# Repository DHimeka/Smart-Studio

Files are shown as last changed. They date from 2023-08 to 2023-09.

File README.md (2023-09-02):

# Smart LED Studio Light System

For the individual project during the fourth semester for the module Electronic Design Realization EN2160, I opted to enhance a Smart LED studio lighting system, primarily tailored for videographers, photographers, and professionals seeking improved lighting solutions. I began with an economical base product, featuring an ESP32 microcontroller. Following a user-centric design methodology, I aimed to rectify existing market deficiencies, introducing heightened luminosity, flexibility, and user-oriented attributes. This specialized lighting system not only targets the need for efficient workspace illumination but also offers stress relief and entertainment, effectively integrating practicality and leisure. The project's objective is to provide an affordable yet comprehensive lighting solution, thereby reshaping the landscape of studio lighting.

## Table of Contents
- [Introduction](#introduction)
- [Problem Statement](#problem-statement)
- [Design Approach](#design-approach)
- [Prototype Design](#prototype-design)
  
   -[PCB Design](#pcb)
  
   -[Enclosure Design](#enclosure)
  
   -[Testing](#test)
  
- [Final Design](#final-design)

- [Suppliers](#suppliers)
- [Assembly Instructions](#assembly-instructions)
- [Future Improvements](#future-improvements)

## Introduction

Welcome to the Smart LED Studio Light System project! As a passionate photographer and videographer, I often found myself in need of high-quality studio lighting that didn't break the bank. This project was born out of that necessity, aiming to provide an affordable, customizable, and user-friendly studio lighting solution. In this `README.md`, I'll guide you through the project and share my journey in creating this versatile lighting system.

## Problem Statement

In my photography and videography work, I encountered the challenge of finding studio lighting that met my specific needs without costing a fortune. The existing commercial solutions were either too expensive or lacked the flexibility and features I desired. This project addresses this issue by offering an accessible DIY alternative that empowers creators to tailor their lighting setup.

## Design Approach

My design approach focused on three key pillars: affordability, versatility, and user-friendliness. To achieve these goals, I conducted thorough research on LED technology, lighting design principles, and user preferences. I also sought inspiration from the maker community, drawing on their creative solutions and feedback to refine my own design.

## Prototype Design

In the early stages, I carefully selected components, considering factors such as LED panel types, power sources, and control interfaces. The prototype development involved creating a functional LED panel design, crafting schematics, and performing initial testing. The insights gained from these initial prototypes allowed me to iterate and refine the design.

## Final Design

The final design of the Smart LED Studio Light System incorporates feedback from fellow photographers and videographers. I enhanced the system by adding Bluetooth connectivity, enabling users to control the lights remotely via a smartphone app. Additionally, I implemented a music visualization feature that synchronizes the lights with audio, creating dynamic and captivating lighting effects. The improved enclosure design ensures durability and aesthetic appeal.

## Suppliers

I sourced the components from reputable suppliers, ensuring the quality and reliability of the materials.

## Assembly Instructions

I've provided detailed step-by-step instructions to help you assemble your Smart LED Studio Light System.Since the device compromises of 2 PCBs
when assembling the device should be concerned about the connecting procedures.
-Power off the switch
-Place the batteries in the battery holder
-Confirm if the appropriate voltages are at headers J20 and J31 using a multi meter, before moving forward.Connect power to ESP and connect
power to the LED panel by connecting appropriate pins
-Connect the signal pins to LED Panel(header P10 in main PCB and P1 header in LED panel PCB)
-Press the power on switch and you can witness the functioning.

## Future Improvements

While the current version of the Smart LED Studio Light System is feature-rich, there are always opportunities for further enhancements. Some ideas for future improvements include:
- Integration with voice assistants for hands-free control.
- Compatibility with a wider range of music sources and platforms.
- Advanced color temperature and brightness presets for different shooting scenarios.
- Collaborative features for synchronized lighting setups in group settings.

## User Manual

For detailed instructions on how to operate your Smart LED Studio Light System, please refer to the user manual provided [here](user-manual.pdf).

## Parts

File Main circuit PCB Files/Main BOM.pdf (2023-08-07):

Line # | Name Description | Designator | Revision ID | Revision State | Revision Status | Manufacturer 1 | Manufacturer Part Number 1 | Manufacturer Lifecycle 1 | Supplier 1 | Supplier Part Number 1 | Supplier Unit Price 1 | Supplier Subtotal 1
| 100nF Bridge Rectifier | BR1 | | Not managed
| Cap Ceramic 100nF 100V CL31B104 KCFNNNE X7R ±10% SMD 1206 +125°C Embossed T/R | C1 | CMP-13271-001514-1 | New From Design | Up to date | Samsung | CL31B104KCFNNNE | Volume Production | Digi-Key | 1276-1151-1-ND | | 0.12 | 0.24
| Cap Ceramic CL31B104 100nF 100V X7R ±10% KCFNNNE SMD 1206 +125°C Embossed T/R | C2 | CMP-13271-001514-1 | New From Design | Up to date | Samsung | CL31B104KCFNNNE | Volume Production | Digi-Key | 1276-1151-1-ND | | 0.12 | 0.24
| CL21B106 CAP CER 10UF 16V X7R 0805 KOQNNNG | C3 | CMP-13271-000015-1 | New From Design | Up to date | Samsung | CL21B106KOQNNNG | Volume Production | Arrow Electronics | CL21B106KOQNNNG | 0.1719 | 0.3438
| EEEFT1E4 71AP CAP ALUM 470UF 20% 25V SMD | C4 | CMP-05427-000040-1 | New From Design | Up to date | Panasonic | EEE-FT1E471AP | Volume Production | Newark | 89Y7242 | | 0.46 | 0.46
| CL21B106 KOQNNNG CAP CER 10UF 16V X7R 0805 | C5 | CMP-13271-000015-1 | New From Design | Up to date | Samsung | CL21B106KOQNNNG | Volume Production | Arrow Electronics | CL21B106KOQNNNG | 0.1719 | 0.3438
68pF 0.1uF Capacitor Capacitor Chip Multilayer GRM31CR 71E106KA Ceramic Capacitors for General 12L Purpose, 1206, 10uF, X7R, 15%, 10%, 25V | C7 C6 C8 | CMP-06035-003589-1 | Not managed Not managed New From Design | Up to date | Murata | GRM31CR71E106KA12L | Volume Production | Mouser | 81-GRM31CR71E106KA12 | 0.29 | 0.29
EMK316BB J476ML-T None | C9 | CMP-14477-000191-2 | New From Design | Up to date | Taiyo Yuden | EMK316BBJ476ML-T | Volume Production | Mouser | 963-EMK316BBJ476ML-T | 0.58 | 0.58
56uF Capacitor Polarised | C10 | | Not managed
100nF Capacitor 120uF Capacitor Polarised | C11 C12 | | Not managed Not managed
15nF Capacitor CL21 Series 0805 220pF CL21C221 JBANNNC 50V ±5% Tolerance C0G Multilayer Ceramic Chip Capacitor | C13 C14 | CMP-13271-001616-1 | Not managed New From Design | Up to date | Samsung | CL21C221JBANNNC | Volume Production | Digi-Key | 1276-1164-1-ND | 0.1 | 0.1
10uF Capacitor CL21 Series 0805 2.2nF 50V CL21C222 JBFNNNE ±5% Tolerance C0G Multilayer Ceramic Chip Capacitor | C15 C16 | CMP-13271-001564-1 | Not managed New From Design | Up to date | Samsung | CL21C222JBFNNNE | End of Life | Arrow Electronics | CL21C222JBFNNNE | 0.0153 | 0.0153
SS36FA Diode | D1 | | Not managed
SML-Yellow LED, Water Clear Len, 585 nm, LX1206YC-TR 2.1 V, -40 to 85 degC, 2-Pin SMD, RoHS, Tape and Reel | DS1 | CMP-2000-07124-1 | Released | Up to date | Lumex | SML-LX1206YC-TR | Volume Production | Mouser | 696-SML-LX1206YC | | 0.36 | 0.36
BLM21PG3 Chip Ferrite Bead, 0805, 30 00SH1D Ω @ 100MHz, 0.014Ω, , 4A | FB1 | CMP-06046-001820-1 | New From Design | Up to date | Murata | BLM21PG300SH1D | Volume Production | Arrow Electronics | BLM21PG300SH1D | 0.0738 | 0.738
BLM21PG3 Chip Ferrite Bead, 0805, 30 00SH1D Ω @ 100MHz, 0.014Ω, , 4A | FB2 | CMP-06046-001820-1 | New From Design | Up to date | Murata | BLM21PG300SH1D | Volume Production | Arrow Electronics | BLM21PG300SH1D | 0.0738 | 0.738
BLM21PG3 Chip Ferrite Bead, 0805, 30 00SH1D Ω @ 100MHz, 0.014Ω, , 4A | FB3 | CMP-06046-001820-1 | New From Design | Up to date | Murata | BLM21PG300SH1D | Volume Production | Arrow Electronics | BLM21PG300SH1D | 0.0738 | 0.738
BLM21PG3 Chip Ferrite Bead, 0805, 30 00SH1D Ω @ 100MHz, 0.014Ω, , 4A | FB4 | CMP-06046-001820-1 | New From Design | Up to date | Murata | BLM21PG300SH1D | Volume Production | Arrow Electronics | BLM21PG300SH1D | 0.0738 | 0.738
BLM21PG3 00SH1D Chip Ferrite Bead, 0805, 30 Ω @ 100MHz, 0.014Ω, , 4A | FB5 | CMP-06046-001820-1 | New From Design | Up to date | Murata | BLM21PG300SH1D | Volume Production | Arrow Electronics | BLM21PG300SH1D | 0.0738 | 0.738
BLM21PG3 00SH1D Chip Ferrite Bead, 0805, 30 Ω @ 100MHz, 0.014Ω, , 4A | FB6 | CMP-06046-001820-1 | New From Design | Up to date | Murata | BLM21PG300SH1D | Volume Production | Arrow Electronics | BLM21PG300SH1D | 0.0738 | 0.738
LMR38020 FDDAR Integrated Circuit | IC1 | | Not managed
LM26003 MH_NOPB Integrated Circuit | IC2 | | Not managed
61301621 THT Vertical Pin Header WR-PHD, Pitch 2.54 121 mm, Dual Row, 16 pins | J1 | CMP-1502-01097-1 | Released | Out of date | Wurth Electronics | 61301621121 | Volume Production | Newark | 20X0981 | 0.318 | 0.318
5000 PC TEST POINT MINIATURE RED | J2 | CMP-19636-000027-1 | New From Design | Up to date | Keystone Electronics | 5000 | Volume Production | Farnell | 2250281 | 0.24385 | | 4.39
61900211 CONN HEADER 121 VERT 2POS 2.54MM | J3 | CMP-1502-00584-2 | Released | Out of date | Wurth Electronics | 61900211121 | Volume Production | Mouser | 710-61900211121 | | 0.54 | 4.32
RAPC722X A, 3-Pin THD, Power Jack, 5 RoHS, Bulk | J4 | CMP-2000-05384-1 | Released | Up to date | Switchcraft | RAPC722X | Volume Production | Newark | 65K7786 | | 1.35 | 2.7
PC TEST POINT 5000 MINIATURE RED | J5 | CMP-19636-000027-1 | New From Design | Up to date | Keystone Electronics | 5000 | Volume Production | Farnell | 2250281 | 0.24385 | | 4.39
5000 PC TEST POINT MINIATURE RED | J6 | CMP-19636-000027-1 | New From Design | Up to date | Keystone Electronics | 5000 | Volume Production | Farnell | 2250281 | 0.24385 | | 4.39
5000 PC TEST POINT MINIATURE RED | J7 | CMP-19636-000027-1 | New From Design | Up to date | Keystone Electronics | 5000 | Volume Production | Farnell | 2250281 | 0.24385 | | 4.39
PC TEST POINT 5000 MINIATURE RED | J8 | CMP-19636-000027-1 | New From Design | Up to date | Keystone Electronics | 5000 | Volume Production | Farnell | 2250281 | 0.24385 | | 4.39
5000 PC TEST POINT MINIATURE RED | J9 | CMP-19636-000027-1 | New From Design | Up to date | Keystone Electronics | 5000 | Volume Production | Farnell | 2250281 | 0.24385 | | 4.39
61900211 121 VERT 2POS CONN HEADER 2.54MM | J10 | CMP-1502-00584-2 | Released | Out of date | Wurth Electronics | 61900211121 | Volume Production | Mouser | 710-61900211121 | | 0.54 | 4.32
PC TEST POINT 5000 MINIATURE RED | J11 | CMP-19636-000027-1 | New From Design | Up to date | Keystone Electronics | 5000 | Volume Production | Farnell | 2250281 | 0.24385 | | 4.39
61900211 121 VERT 2POS CONN HEADER 2.54MM | J12 | CMP-1502-00584-2 | Released | Out of date | Wurth Electronics | 61900211121 | Volume Production | Mouser | 710-61900211121 | | 0.54 | 4.32
Power Jack, 5 RAPC722X A, 3-Pin THD, RoHS, Bulk | J13 | CMP-2000-05384-1 | Released | Up to date | Switchcraft | RAPC722X | Volume Production | Newark | 65K7786 | | 1.35 | 2.7
5000 PC TEST POINT MINIATURE RED | J14 | CMP-19636-000027-1 | New From Design | Up to date | Keystone Electronics | 5000 | Volume Production | Farnell | 2250281 | 0.24385 | | 4.39
61900211 121 VERT 2POS CONN HEADER 2.54MM | J15 | CMP-1502-00584-2 | Released | Out of date | Wurth Electronics | 61900211121 | Volume Production | Mouser | 710-61900211121 | | 0.54 | 4.32
61900211 CONN HEADER 121 VERT 2POS 2.54MM | J16 | CMP-1502-00584-2 | Released | Out of date | Wurth Electronics | 61900211121 | Volume Production | Mouser | 710-61900211121 | | 0.54 | 4.32
5000 PC TEST POINT MINIATURE RED | J17 | CMP-19636-000027-1 | New From Design | Up to date | Keystone Electronics | 5000 | Volume Production | Farnell | 2250281 | 0.24385 | | 4.39
5000 PC TEST POINT MINIATURE RED | J18 | CMP-19636-000027-1 | New From Design | Up to date | Keystone Electronics | 5000 | Volume Production | Farnell | 2250281 | 0.24385 | | 4.39
PC TEST POINT 5000 MINIATURE RED | J19 | CMP-19636-000027-1 | New From Design | Up to date | Keystone Electronics | 5000 | Volume Production | Farnell | 2250281 | 0.24385 | | 4.39
61900211 121 VERT 2POS CONN HEADER 2.54MM | J20 | CMP-1502-00584-2 | Released | Out of date | Wurth Electronics | 61900211121 | Volume Production | Mouser | 710-61900211121 | | 0.54 | 4.32
PC TEST POINT 5000 MINIATURE RED | J21 | CMP-19636-000027-1 | New From Design | Up to date | Keystone Electronics | 5000 | Volume Production | Farnell | 2250281 | 0.24385 | | 4.39
5000 PC TEST POINT MINIATURE RED | J22 | CMP-19636-000027-1 | New From Design | Up to date | Keystone Electronics | 5000 | Volume Production | Farnell | 2250281 | 0.24385 | | 4.39
5000 PC TEST POINT MINIATURE RED | J23 | CMP-19636-000027-1 | New From Design | Up to date | Keystone Electronics | 5000 | Volume Production | Farnell | 2250281 | 0.24385 | | 4.39
PC TEST POINT 5000 MINIATURE RED | J24 | CMP-19636-000027-1 | New From Design | Up to date | Keystone Electronics | 5000 | Volume Production | Farnell | 2250281 | 0.24385 | | 4.39
5000 PC TEST POINT MINIATURE RED | J25 | CMP-19636-000027-1 | New From Design | Up to date | Keystone Electronics | 5000 | Volume Production | Farnell | 2250281 | 0.24385 | | 4.39
PC TEST POINT 5000 MINIATURE RED | J26 | CMP-19636-000027-1 | New From Design | Up to date | Keystone Electronics | 5000 | Volume Production | Farnell | 2250281 | 0.24385 | | 4.39
5000 PC TEST POINT MINIATURE RED | J27 | CMP-19636-000027-1 | New From Design | Up to date | Keystone Electronics | 5000 | Volume Production | Farnell | 2250281 | 0.24385 | | 4.39
5001 PC TEST POINT MINIATURE BLACK | J28 | CMP-2000-05181-2 | Released | Up to date | Keystone Electronics | 5001 | Volume Production | Farnell | 2301278 | 0.25235 | 0.50469
PC TEST POINT 5001 MINIATURE BLACK | J29 | CMP-2000-05181-2 | Released | Up to date | Keystone Electronics | 5001 | Volume Production | Farnell | 2301278 | 0.25235 | 0.50469
61900211 VERT 2POS CONN HEADER 121 2.54MM | J30 | CMP-1502-00584-2 | Released | Out of date | Wurth Electronics | 61900211121 | Volume Production | Mouser | 710-61900211121 | | 0.54 | 4.32
61900211 121 VERT 2POS CONN HEADER 2.54MM | J31 | CMP-1502-00584-2 | Released | Out of date | Wurth Electronics | 61900211121 | Volume Production | Mouser | 710-61900211121 | | 0.54 | 4.32
SRR1260-FIXED IND 150M 15UH 5A 27 MOHM SMD | L1 | CMP-2000-07146-2 | Released | Up to date | Bourns | SRR1260-150M | Volume Production | Newark | 38AC2402 | 0.669 | 0.669
15uH Inductor ESP32-WIFI MODULE WROOM-32D 32MBITS SPI FLASH | L2 MCU1 | CMP-194065-000003-1 | Not managed New From Design | Up to date | Espressif Systems | ESP32-WROOM-32D | Not Recommended for New Design
0.025" SQ Post Header, TSW-103-Vertical, -55 to Through-hole, 07-F-S 125 degC, 2.54 mm Pitch, 3-Pin, Male, RoHS | P1 | CMP-1024-00331-1 | Released | Up to date | Samtec | TSW-103-07-F-S | Volume Production | Arrow Electronics | TSW-103-07-F-S | 0.32 | 2.56
0.025" SQ Post Header, Through-hole, TSW-103-07-F-S Vertical, -55 to 125 degC, 2.54 mm Pitch, 3-Pin, Male, RoHS | P2 | CMP-1024-00331-1 | Released | Up to date | Samtec | TSW-103-07-F-S | Volume Production | Arrow Electronics | TSW-103-07-F-S | 0.32 | 2.56
0.025" SQ Post TSW-103-Vertical, -55 to Header, Through-hole, 07-F-S 125 degC, 2.54 mm Pitch, 3-Pin, Male, RoHS | P3 | CMP-1024-00331-1 | Released | Up to date | Samtec | TSW-103-07-F-S | Volume Production | Arrow Electronics | TSW-103-07-F-S | 0.32 | 2.56

Line # | Name | Description | Designator | Revision ID | Revision State | Revision Status | Manufacturer 1 | Manufacturer Part Number 1 | Manufacturer Lifecycle 1 | Supplier 1 | Supplier Part Number 1 | Supplier Unit Price 1 | Supplier Subtotal 1
0.025" SQ Post Header, TSW-103-Vertical, -55 to Through-hole, 07-F-S 125 degC, 2.54 mm Pitch, 3-Pin, Male, RoHS | P4 | CMP-1024-00331-1 | Released | Up to date | Samtec | TSW-103-07-F-S | Volume Production | Arrow Electronics | TSW-103-07-F-S | | 0.32 | 2.56
0.025" SQ Post Header, Through-hole, TSW-103-07-F-S Vertical, -55 to 125 degC, 2.54 mm Pitch, 3-Pin, Male, RoHS | P5 | CMP-1024-00331-1 | Released | Up to date | Samtec | TSW-103-07-F-S | Volume Production | Arrow Electronics | TSW-103-07-F-S | | 0.32 | 2.56
0.025" SQ Post Header, TSW-104-Vertical, -55 to Through-hole, 08-G-S 125 degC, 2.54 mm Pitch, 4-Pin, Male, RoHS | P6 | CMP-1024-00357-1 | Released | Up to date | Samtec | TSW-104-08-G-S | Volume Production | Avnet | TSW-104-08-G-S | 0.2844 | 0.2844
0.025" SQ Post Header, Through-hole, TSW-103-07-F-S Vertical, -55 to 125 degC, 2.54 mm Pitch, 3-Pin, Male, RoHS | P7 | CMP-1024-00331-1 | Released | Up to date | Samtec | TSW-103-07-F-S | Volume Production | Arrow Electronics | TSW-103-07-F-S | | 0.32 | 2.56
61300411 THT Vertical Pin Header WR-121 PHD, Pitch 2.54 mm, Single Row, 4 pins | P8 | CMP-1502-01064-1 | Released | Out of date | Wurth Electronics | 61300411121 | Volume Production | Digi-Key | 732-5317-ND | | 0.19 | 0.19
0.025" SQ Post Header, TSW-103-07-F-S Vertical, -55 to Through-hole, 125 degC, 2.54 mm Pitch, 3-Pin, Male, RoHS | P9 | CMP-1024-00331-1 | Released | Up to date | Samtec | TSW-103-07-F-S | Volume Production | Arrow Electronics | TSW-103-07-F-S | | 0.32 | 2.56
0.025" SQ Post TSW-103-Vertical, -55 to Header, Through-hole, 07-F-S 125 degC, 2.54 mm Pitch, 3-Pin, Male, RoHS | P10 | CMP-1024-00331-1 | Released | Up to date | Samtec | TSW-103-07-F-S | Volume Production | Arrow Electronics | TSW-103-07-F-S | | 0.32 | 2.56
IRF7316T RPBF MOSFET 2P-CH 30V 4.9A 8-SOIC | Q1 | CMP-32901-000528-1 | New From Design | Up to date | Infineon | IRF7316TRPBF | Obsolete | Arrow Electronics | IRF7316TRPBF | 0.5868 | 0.5868
General Purpose Transistor, NPN 2N3904 Silicon, 200 mA, 60 V, -55 to 150 degC, 3-Pin TO-92, RoHS, Bulk | Q2 | CMP-2000-05562-1 | Released | Up to date | ON Semiconductor / Fairchild | 2N3904 | Obsolete
Chip Resistor, 10 KOhm, +/-RC1206FR-1%, 0.25 W, -55 to 155 0710KL degC, 1206 (3216 Metric), RoHS, Tape and Reel | R1 | CMP-1014-00623-2 | Released | Up to date | Bourns | CR1206-FX-1002ELF | Volume Production | Newark | 84W7259 | 0.006 | 0.048
Chip Resistor, 10 KOhm, +/-1%, 0.25 W, -RC1206FR-0710KL 55 to 155 degC, 1206 (3216 Metric), RoHS, Tape and Reel | R2 | CMP-1014-00623-2 | Released | Up to date | Bourns | CR1206-FX-1002ELF | Volume Production | Newark | 84W7259 | 0.006 | 0.048
Chip Resistor, 10 KOhm, +/-RC1206FR-1%, 0.25 W, -55 to 155 0710KL degC, 1206 (3216 Metric), RoHS, Tape and Reel | R3 | CMP-1014-00623-2 | Released | Up to date | Bourns | CR1206-FX-1002ELF | Volume Production | Newark | 84W7259 | 0.006 | 0.048
Chip Resistor, 10 KOhm, +/-1%, 0.25 W, -RC1206FR-0710KL 55 to 155 degC, 1206 (3216 Metric), RoHS, Tape and Reel | R4 | CMP-1014-00623-2 | Released | Up to date | Bourns | CR1206-FX-1002ELF | Volume Production | Newark | 84W7259 | 0.006 | 0.048
Chip Resistor, RC1206FR-10 KOhm, +/-1%, 0.25 W, -55 to 155 0710KL degC, 1206 (3216 Metric), RoHS, Tape and Reel | R5 | CMP-1014-00623-2 | Released | Up to date | Bourns | CR1206-FX-1002ELF | Volume Production | Newark | 84W7259 | 0.006 | 0.048
CRCW120 RES Thick Film, 1.5kΩ, 1%, A 61K50FKE 0.25W, 100ppm/°C, 1206 | R6 | CMP-02407-002229-1 | New From Design | Up to date | Vishay | CRCW12061K50FKEA | Volume Production | Newark | 24W3925 | 0.015 | 0.015
Chip Resistor, 10 KOhm, +/-1%, 0.25 W, -RC1206FR-0710KL 55 to 155 degC, 1206 (3216 Metric), RoHS, Tape and Reel | R7 | CMP-1014-00623-2 | Released | Up to date | Bourns | CR1206-FX-1002ELF | Volume Production | Newark | 84W7259 | 0.006 | 0.048
Chip Resistor, RC1206FR-10 KOhm, +/-1%, 0.25 W, -55 to 155 0710KL degC, 1206 (3216 Metric), RoHS, Tape and Reel | R8 | CMP-1014-00623-2 | Released | Up to date | Bourns | CR1206-FX-1002ELF | Volume Production | Newark | 84W7259 | 0.006 | 0.048
Chip Resistor, 100 KOhm, +/-RC1206FR-07100KL 1%, 0.25 W, -55 to 155 degC, 1206 (3216 Metric), RoHS, Tape and Reel | R9 | CMP-2100-03674-1 | Released | Up to date | Yageo | RC1206FR-07100KL | Volume Production | Newark | 12AC2242 | 0.006 | 0.006
100K 100K Resistor Resistor 23.2K Resistor 10K 64.9K Resistor Resistor CRCW120 A 6205KFKE | R11 R10 R12 R14 R13 R15 | CMP-2003-01938-1 | Not managed Not managed Not managed Not managed Not managed Released | Up to date | Vishay | CRCW1206205KFKEA | Volume Production | Newark | 53K2139 | 0.002 | 0.002
ERJ-V 6ENF2052 | R16 | CMP-2001-00032-1 | Released | Up to date | Panasonic | ERJ-6ENF2052V | Volume Production | Arrow Electronics | ERJ-6ENF2052V | 0.0515 | 0.0515
Chip Resistor, 10 KOhm, +/-1%, 0.125 W, -RC0805FR-0710KL 55 to 155 degC, 0805 (2012 Metric), RoHS, Tape and Reel | R17 | CMP-1659-00013-4 | Released | Up to date | Yageo | RC0805FR-0710KL | Volume Production | Newark | 85X1799 | 0.004 | 0.004
ERJ-8ENF1542 V | R18 | CMP-2003-00123-1 | Released | Up to date | Panasonic | ERJ-8ENF1542V | Not Recommended for New Design | Newark | 90W3653 | 0.008 | 0.008
Chip Resistor, 10 KOhm, +/-RC1206FR-1%, 0.25 W, -55 to 155 0710KL degC, 1206 (3216 Metric), RoHS, Tape and Reel | R19 | CMP-1014-00623-2 | Released | Up to date | Bourns | CR1206-FX-1002ELF | Volume Production | Newark | 84W7259 | 0.006 | 0.048
ERA-V 8AEB1333 | R20 | CMP-2003-04387-1 | Released | Up to date | Panasonic | ERA-8AEB1333V | Volume Production | Digi-Key | 10-ERA-8AEB1333VCT-ND | | 0.61 | 0.61
FSMSM Switch | S1 | | Not managed
FSMSM Switch | S2 | | Not managed
LTC4412E IC OR CTRLR S6#TRMP BF SRC SELECT TSOT23-6 | U1 | CMP-0479-00425-2 | Released | Up to date | Analog Devices / Linear Technology | LTC4412ES6#TRMPBF | Volume Production | Farnell | 4026046 | | 4.53 | 4.53

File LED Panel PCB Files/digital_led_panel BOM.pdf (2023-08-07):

Line # | Name | Description | Designator | Revision ID | Revision State | Revision Status | Quantity | Manufacturer 1 | Manufacturer Part Number 1 | Manufacturer Lifecycle 1 | Supplier 1 | Supplier Part Number 1 | Supplier Unit Price 1 | Supplier Subtotal 1
| C1206C104K5RACTU | CAP, Ceramic, 0.1 uF, +/-10%, 50 V, -55 to 125 degC, 1206 (3216 Metric), RoHS, Tape and Reel | C1, C2, C3, C4, C5, C7, C8, C9, C10, C11, C14, C15, C16, C17, C18, C19, C20, C21, C22, C23 | CMP-1037-04202-2 | Released | Up to date | 20 KEMET | | C1206C104K5RACTM | Volume Production | Newark | 96Y7250 | 0.02 | 0.4
| 1206ZD106KAT2A | General Purpose Ceramic Capacitor, 1206, 10uF, 10%, X5R, 15%, 10V | C6 | CMP-04427-021870-1 | New From Design | Up to date | 1 Kyocera AVX | | 1206ZD106KAT2A | Volume Production | Arrow Electronics | 1206ZD106KAT2A | 0.5108 | 0.5108
| C1206C104K1RACTU | CAP CER 0.1UF 100V X7R 1206 C12 | | CMP-03020-000153-1 | New From Design | Up to date | 1 KEMET | | C1206C104K1RACTU | Volume Production | Newark | 70K9165 | 0.051 | 0.051
| 100uF | Capacitor Polarised | C13 | | Not managed | | 1
| BLM21PG300SH1D | Chip Ferrite Bead, 0805, 30 Ω @ 100MHz, 0.014Ω, , 4A | FB1, FB2 | CMP-06046-001820-1 | New From Design | Up to date | 2 Murata | | BLM21PG300SH1D | Volume Production | Arrow Electronics | BLM21PG300SH1D | 0.1406 | 0.2812
| 5000 | PC TEST POINT MINIATURE RED | J1, J2 | CMP-19636-000027-1 | New From Design | Up to date | 2 | Keystone Electronics | 5000 | Volume Production | Farnell | 2250281 | 0.25235 | 0.50469
| 5001 | PC TEST POINT MINIATURE BLACK | J3 | CMP-2000-05181-2 | Released | Up to date | 1 | Keystone Electronics | 5001 | Volume Production | Farnell | 2301278 | 0.25235 | 0.25235
| 61300811121 | THT Vertical Pin Header WR-PHD, Pitch 2.54 mm, Single Row, 8 pins | P1 | CMP-1502-01076-1 | Released | Out of date | 1 Wurth Electronics | | 61300811121 | Volume Production | Digi-Key | 732-5321-ND | 0.4 | 0.4
| RC1206FR-0710KL | Chip Resistor, 10 KOhm, +/-1%, 0.25 W, -55 to 155 degC, 1206 (3216 Metric), RoHS, Tape and Reel | R1 | CMP-1014-00623-2 | Released | Up to date | 1 Bourns | | CR1206-FX-1002ELF | Volume Production | Newark | 84W7259 | 0.006 | 0.006
| ERJ-8ENF3401V | | R2 | CMP-2003-00314-1 | Released | Up to date | 1 Panasonic | | ERJ-8ENF3401V | Not Recommended for New Design | Arrow Electronics | ERJ-8ENF3401V | 0.0307 | 0.0307
| 1655 | Intelligent Control LED Integrated Light Source, 3.5 to 5.3 V, -25 to 80 degC, 4-Pin SMD, RoHS, Tape and Reel | U1, U2, U3, U4, U5, U6, U7, U8, U9, U10, U12, U13, U14, U15, U16, U17, U18, U19, U20, U21 | CMP-2000-05026-1 | Released | Up to date | 20 Adafruit Industries | | 1655 | Unknown | Mouser | 485-1655 | 4.5 | 90
| AP22615AWU-7 | IC PWR SWTCH N/P-CHAN 1:1 TSOT26 | U11 | CMP-12757-000023-1 | New From Design | Up to date | 1 Diodes | | AP22615AWU-7 | Volume Production | Arrow Electronics | AP22615AWU-7 | 0.8008 | 0.8008

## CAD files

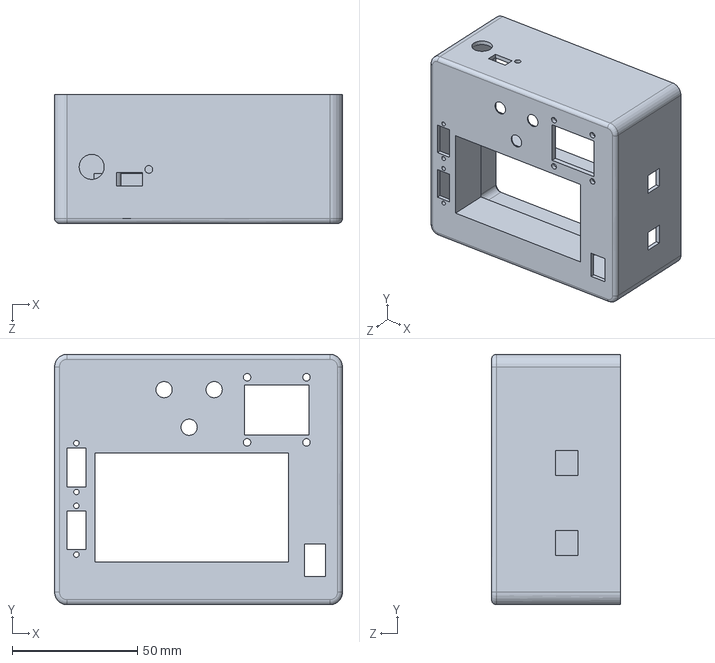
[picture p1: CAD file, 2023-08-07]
Solidworks/Bottim3.SLDPRT
115.0 x 100.0 x 51.5 mm

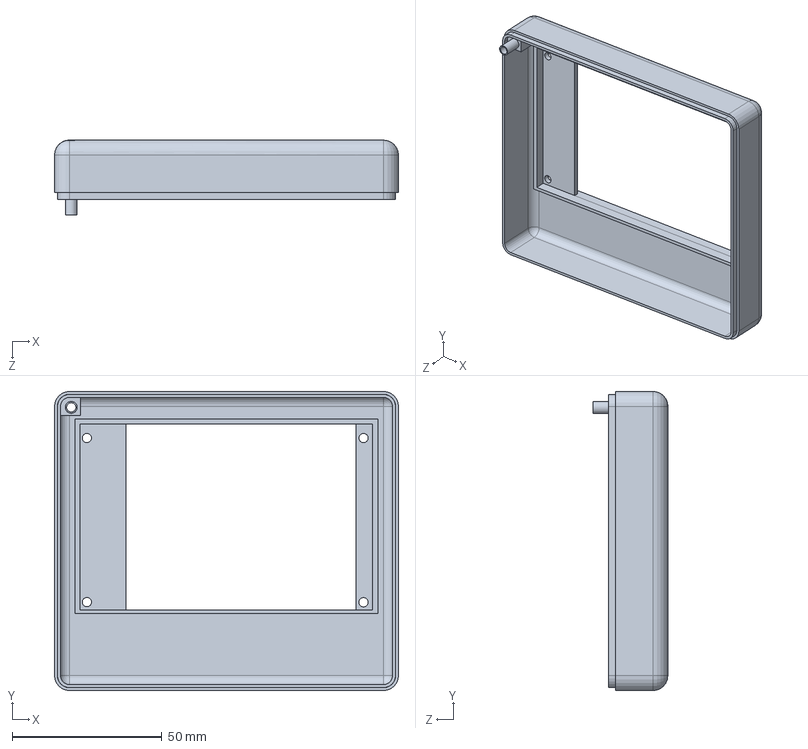
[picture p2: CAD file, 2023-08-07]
Solidworks/Top3.SLDPRT
115.0 x 100.0 x 25.0 mm

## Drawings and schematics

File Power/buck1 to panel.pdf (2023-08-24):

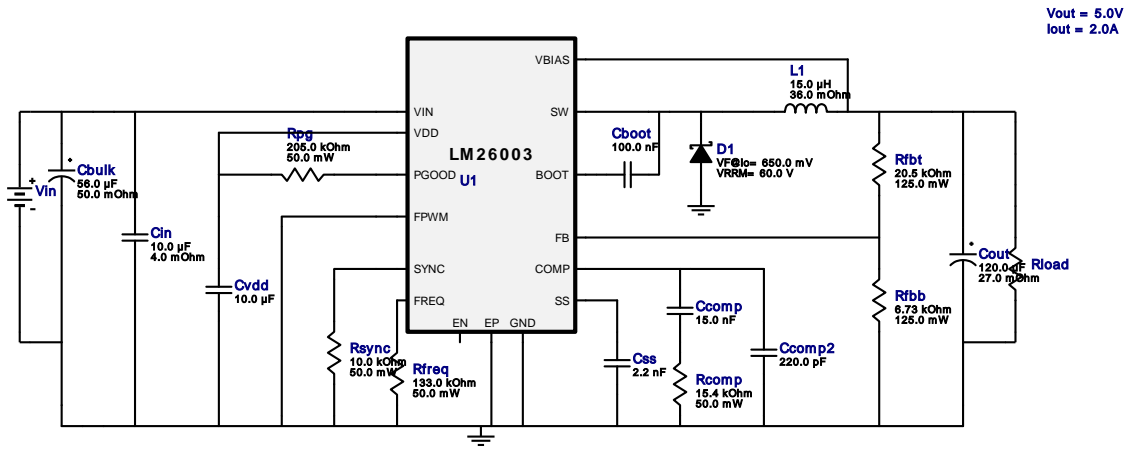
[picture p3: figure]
Ccom p2 220.0 pF; Cbulk 56.0 µF 50.0 m Ohm; Ccom p 15.0 nF; Cin 10.0 µF 4.0 m Ohm; Css 2.2 nF; D1 VF@Io= 650.0 m V VRRM= 60.0 V; L1 15.0 µH 36.0 m Ohm; Rcom p 15.4 kOhm 50.0 m W; Rfbt 20.5 kOhm 125.0 m W; Rfreq 133.0 kOhm 50.0 m W; Rpg 205.0 kOhm 50.0 m W; Rsync 10.0 kOhm 50.0 m W; Cboot 100.0 nF; Cout 120.0 µF 27.0 m Ohm Cvdd; Rfbb; 6.73 kOhm 125.0 m W; VIN; PGOOD; COMP; GND; FREQ; FPWM; SYNC; VBIAS; VDD; BOOT; Vout = 5.0V Iout = 2.0A; Rload; Vin

Copyright © 2023, Texas Instruments Incorporated | 1 | ti.com/webench

WEBENCH®
Design Report LM26003MHX/NOPB : LM26003MHX/NOPB 6V-10V to 5.00V @ 2A April 21, 2023 15:24:57 GMT-05:00

## WEBENCH ® Design Report

Design : 12 LM26003MHX/NOPB
LM26003MHX/NOPB 6V-10V to 5.00V @ 2A

VinMin = 6.0V
VinMax = 10.0V
Vout = 5.0V
Iout = 2.0A

Device = LM26003MHX/NOPB
Topology = Buck
Created = 2023-04-21 10:11:07.004 BOM Cost = $2.87
BOM Count = 17
Total Pd = 0.77W

## Electrical BOM

Name | Manufacturer | Part Number | Properties | Qty Price | Footprint
Cboot | AVX | 08053C104JAZ2A (http://catalogs.avx.com/SurfaceMount.pdf) Series= X7R | Cap= 100.0 nF VDC= 25.0 V IRMS= 0.0 A
1 | $0.07
| | | | | 0805 7 mm²
Cbulk | Panasonic | EEHZC1E560P Series= ZC | Cap= 56.0 uF ESR= 50.0 mOhm VDC= 25.0 V IRMS= 900.0 mA
1 | $0.29
| | | | | SM_RADIAL_6.3AMM 80 mm²
Ccomp | TDK | C2012C0G1H153J085AA (http://product.tdk.com/capacitor/mlcc/en/documents/mlcc%5Fcommercial%5Fgeneral%5Fen.pdf) Series= C0G/NP0 | Cap= 15.0 nF VDC= 50.0 V IRMS= 0.0 A
1 | $0.06
| | | | | 0805 7 mm²
Ccomp2 | Samsung Electro- Mechanics | CL21C221JBANNNC (http://www.samsungsem.com/servlet/FileDownload?type%3Dspec%26file%3DCL21C221JBANNNC.pdf) Series= C0G/NP0 | Cap= 220.0 pF VDC= 50.0 V IRMS= 0.0 A
1 | $0.01
| | | | | 0805 7 mm²
Cin | MuRata | GRM21BR61E106MA73L Series= X5R | Cap= 10.0 uF ESR= 4.0 mOhm VDC= 25.0 V IRMS= 2.8 A
1 | $0.04
| | | | | 0805 7 mm²
Cout | Panasonic | 10SVPC120M
Series= SVPC

Cap= 120.0 uF
ESR= 27.0 mOhm
VDC= 10.0 V
IRMS= 2.32 A

1 $0.46

SM_RADIAL_6.3AMM 80
mm²
Css | Samsung Electro-
Mechanics

CL21C222JBFNNNE (http://www.samsungsem.com/servlet/FileDownload?type%3Dspec%26file%3DCL21C222JBFNNNE.pdf)
Series= C0G/NP0

Cap= 2.2 nF
VDC= 50.0 V
IRMS= 0.0 A

1 $0.02
0805 7 mm²

Cvdd Samsung Electro-Mechanics

CL10A106MQ8NNNC (http://www.samsungsem.com/kr/front/downloadcms.do)
Series= X5R

Cap= 10.0 uF
VDC= 6.3 V
IRMS= 0.0 A

1 $0.02
0603 5 mm²
D1 | Fairchild Semiconductor FSV360FP | VF@Io= 650.0 mV
VRRM= 60.0 V

1 $0.13
SOD-123HE 13 mm²

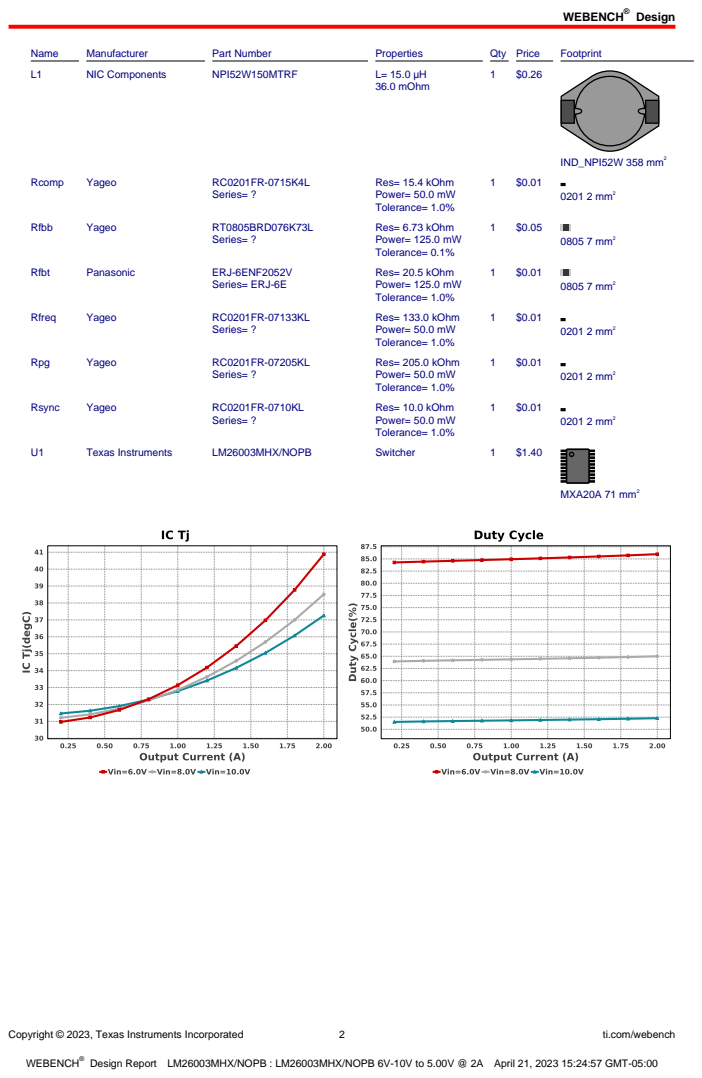
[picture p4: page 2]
Design; Copyright © 2023, Texas Instruments Incorporated; ti.com/webench; Name; Manufacturer; Part Number; Properties; Qty Price; Footprint; NIC Components; NPI52W150MTRF; 36.0 mOhm; IND_NPI52W 358 mm²; Rcomp; Yageo; Series= ?; Res= 15.4 kOhm Power= 50.0 mW Tolerance= 1.0%; 0201 2 mm²; Rfbb; RT0805BRD076K73L; Res= 6.73 kOhm Power= 125.0 mW Tolerance= 0.1%; 0805 7 mm²; Rfbt; Panasonic; ERJ-6ENF2052V; Series= ERJ-6E; Res= 20.5 kOhm Power= 125.0 mW Tolerance= 1.0%; Rfreq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

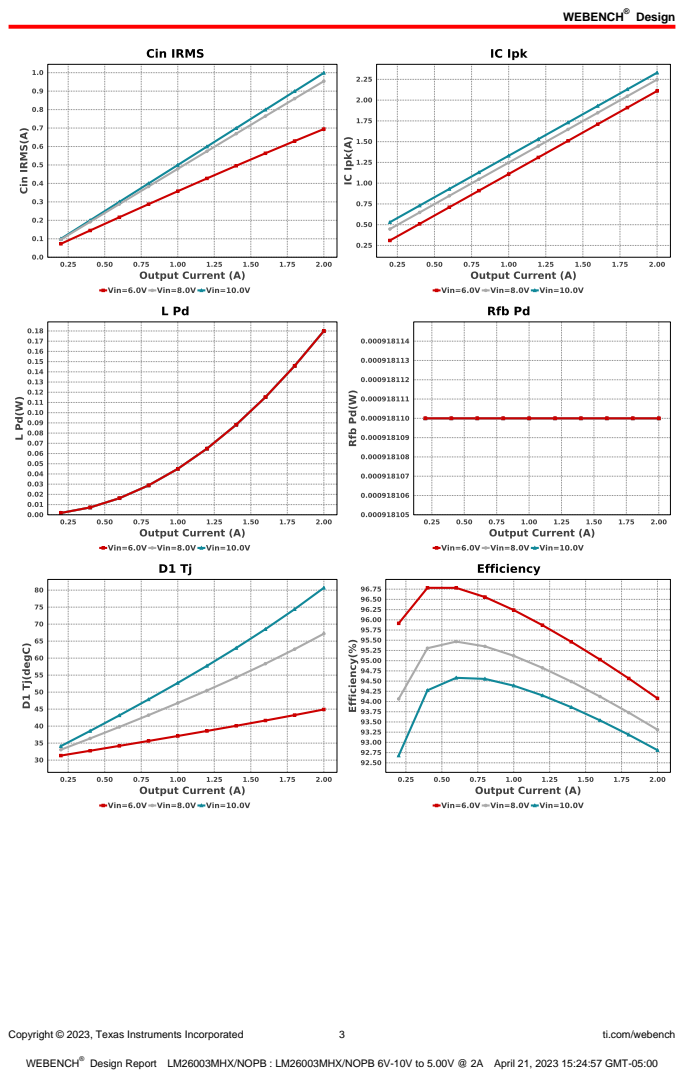
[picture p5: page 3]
Copyright © 2023, Texas Instruments Incorporated; ti.com/webench

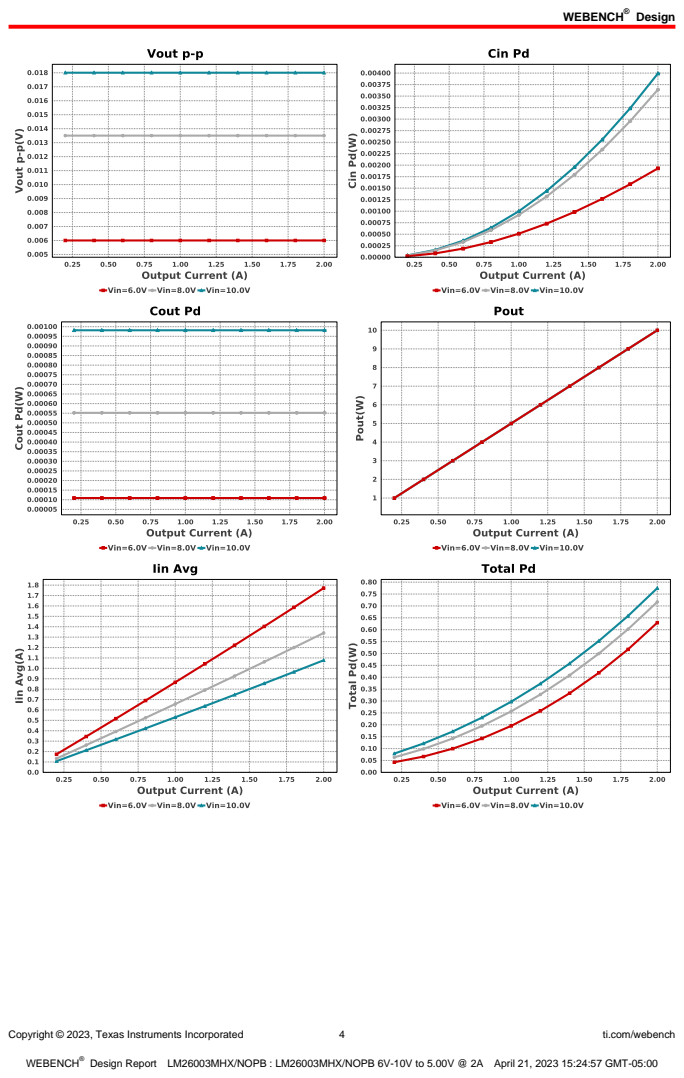
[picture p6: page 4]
Copyright © 2023, Texas Instruments Incorporated; ti.com/webench

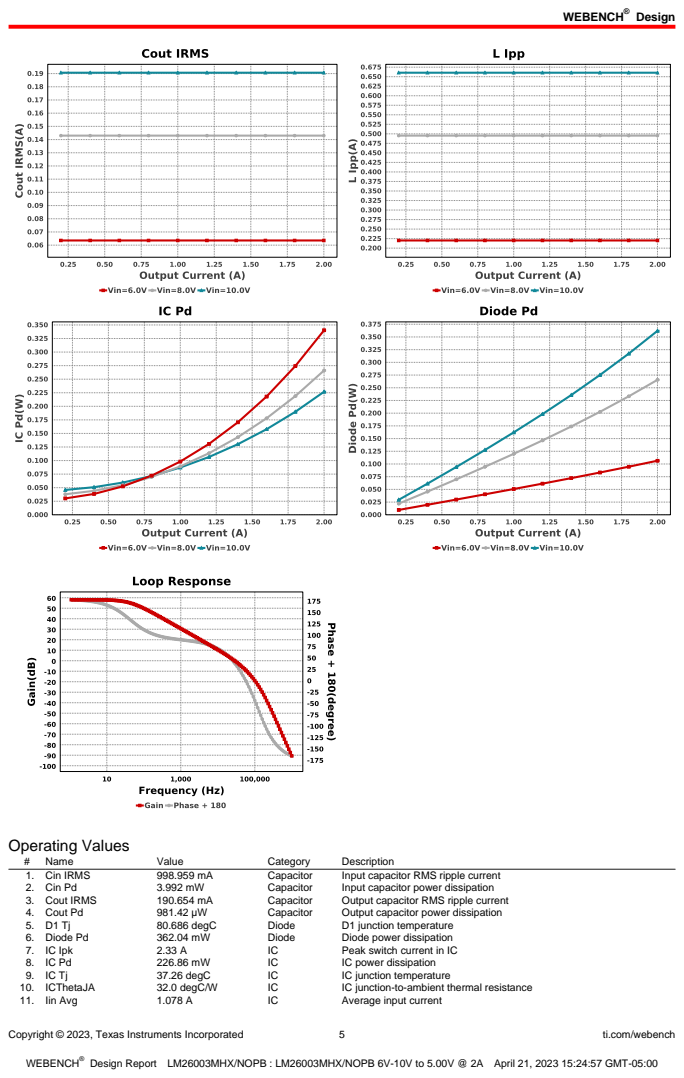
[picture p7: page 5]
Copyright © 2023, Texas Instruments Incorporated; ti.com/webench; Operating Values; Name; Value; Category; Description; 1. Cin IRMS; Capacitor; Input capacitor RMS ripple current; 2. Cin Pd; Input capacitor power dissipation; 3. Cout IRMS; Output capacitor RMS ripple current; 4. Cout Pd; Output capacitor power dissipation; 80.686 degC; Diode; D1 junction temperature; 6. Diode Pd; Diode power dissipation; 7. IC Ipk; Peak switch current in IC; IC power dissipation; 37.26 degC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

Copyright © 2023, Texas Instruments Incorporated | 6 | ti.com/webench
# | Name | Value | Category | Description

12. L Ipp | 660.44 mA | Inductor | Peak-to-peak inductor ripple current
13. L Pd | 180.0 mW | Inductor | Inductor power dissipation
14. Cin Pd | 3.992 mW | Power | Input capacitor power dissipation
15. Cout Pd | 981.42 µW | Power | Output capacitor power dissipation
16. Diode Pd | 362.04 mW | Power | Diode power dissipation
17. IC Pd | 226.86 mW | Power | IC power dissipation
18. L Pd | 180.0 mW | Power | Inductor power dissipation
19. Rfb Pd | 918.11 µW | Power | Rfb Power Dissipation
20. Total Pd | 774.83 mW | Power | Total Power Dissipation
21. Rfb Pd | 918.11 µW | Resistor | Rfb Power Dissipation
22. BOM Count | 17 | System
| | | Information | Total Design BOM count
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

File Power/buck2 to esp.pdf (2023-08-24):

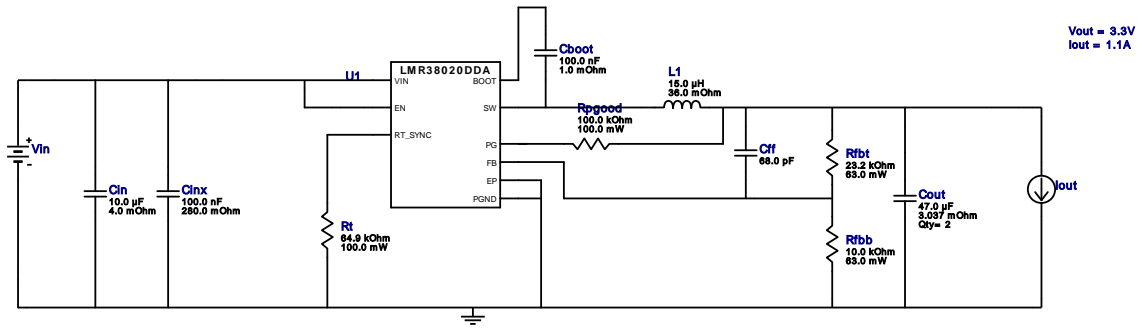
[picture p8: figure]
Vout = 3.3V Iout = 1.1A; Cff 68.0 pF; Rpgood 100.0 kOhm 100.0 m W; Rfbt 23.2 kOhm 63.0 m W; Rfbb 10.0 kOhm 63.0 m W; Cboot 100.0 nF 1.0 m Ohm; Cinx 100.0 nF; 280.0 m Ohm; 64.9 kOhm 100.0 m W; L1 15.0 µH 36.0 m Ohm; Cout 47.0 µF 3.037 m Ohm Qty= 2; Cin 10.0 µF 4.0 m Ohm; LM R3 8 0 2 0 DDA; PGND; VIN; RT_SYNC; BOOT; Vin; Iout

Copyright © 2023, Texas Instruments Incorporated | 1 | ti.com/webench

WEBENCH®
Design Report LMR38020DDAR : LMR38020DDAR 6V-10V to 3.30V @ 1.1A April 21, 2023 14:09:53 GMT-05:00

## WEBENCH ® Design Report

Design : 27 LMR38020DDAR
LMR38020DDAR 6V-10V to 3.30V @ 1.1A

VinMin = 6.0V
VinMax = 10.0V
Vout = 3.3V
Iout = 1.1A

Device = LMR38020DDAR
Topology = Buck
Created = 2023-04-21 14:07:52.100 BOM Cost = $1.33
BOM Count = 12
Total Pd = 0.4W

### Design Alerts

Component Selection Information
This device can work in steady state at Vin = 4.2V. However, needs a minimum of 4.5V during start up. See datasheet for details.

## Electrical BOM

Name | Manufacturer | Part Number | Properties | Qty Price | Footprint
Cboot | MuRata | GRM155R71C104KA88D (http://search.murata.co.jp/Ceramy/PnsearchViewAction.do) Series= X7R | Cap= 100.0 nF ESR= 1.0 mOhm VDC= 16.0 V IRMS= 0.0 A
1 | $0.01
| | | | | 0402 3 mm²
Cff | TDK | CGA1A2C0G1E680J030BA (http://product.tdk.com/capacitor/mlcc/en/documents/mlcc%5Fautomotive%5Fgeneral%5Fen.pdf) Series= C0G/NP0

Cap= 68.0 pF
VDC= 25.0 V
IRMS= 0.0 A

1 $0.01
0201 2 mm²
Cin | MuRata | GRM31CR71E106KA12L Series= X7R

Cap= 10.0 uF
ESR= 4.0 mOhm
VDC= 25.0 V
IRMS= 6.0 A

1 $0.06
1206_180 11 mm²
Cinx | AVX | 08053C104KAT2A (http://datasheets.avx.com/X7RDielectric.pdf) Series= X7R

Cap= 100.0 nF
ESR= 280.0 mOhm
VDC= 25.0 V
IRMS= 0.0 A

1 $0.01
0805 7 mm²
Cout | MuRata | GRM32ER61C476KE15L (http://psearch.en.murata.com/capacitor/result/smd/?status%3Dall%26pid%3DGRM32ER61C476KE15L) Series= X5R | Cap= 47.0 uF ESR= 3.037 mOhm VDC= 16.0 V IRMS= 4.59346 A
2 | $0.17
1210_280 15 mm²
L1 | NIC Components | NPI52W150MTRF (http://www.niccomp.com/pn/NPI52W150MTRF) | L= 15.0 µH 36.0 mOhm
1 | $0.26

IND_NPI52W 358 mm²
Rfbb | Vishay-Dale | CRCW040210K0FKED (http://www.vishay.com/docs/20035/dcrcwe3.pdf) Series= CRCW..e3

Res= 10.0 kOhm
Power= 63.0 mW
Tolerance= 1.0%

1 $0.01
0402 3 mm²
Rfbt | Vishay-Dale | CRCW040223K2FKED (http://www.vishay.com/docs/20035/dcrcwe3.pdf) Series= CRCW..e3

Res= 23.2 kOhm
Power= 63.0 mW
Tolerance= 1.0%

1 $0.01
0402 3 mm²

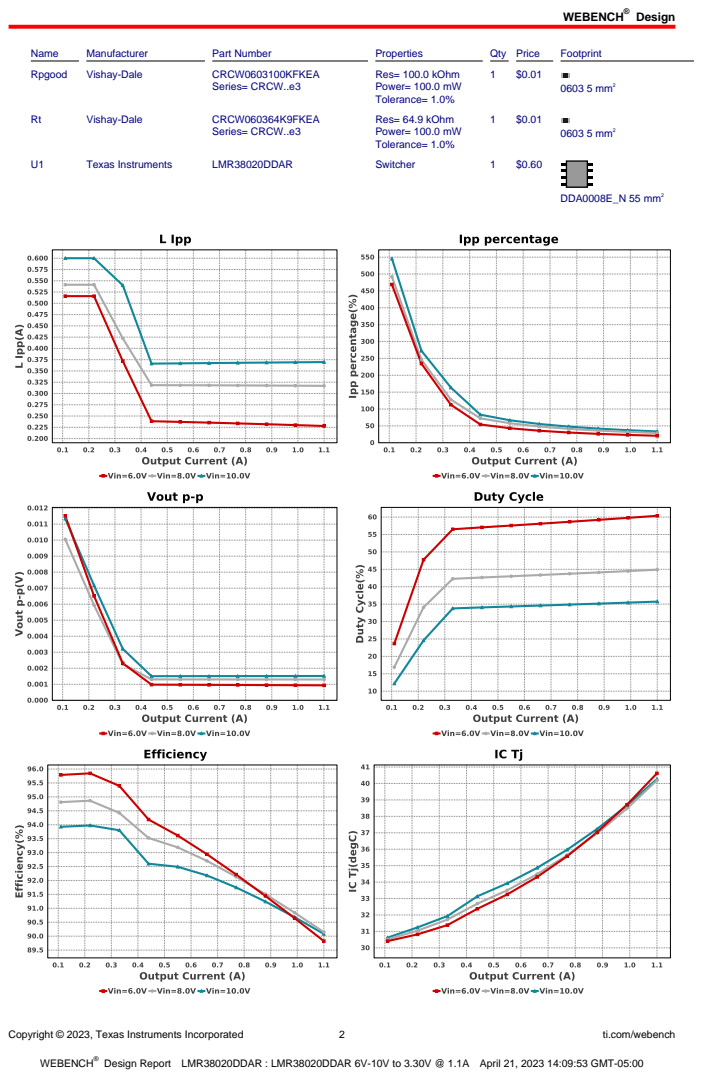
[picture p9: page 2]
Design; Copyright © 2023, Texas Instruments Incorporated; ti.com/webench; Name; Manufacturer; Part Number; Properties; Qty Price; Footprint; Rpgood; Vishay-Dale; CRCW0603100KFKEA; Series= CRCW..e3; Res= 100.0 kOhm Power= 100.0 mW Tolerance= 1.0%; 0603 5 mm²; CRCW060364K9FKEA; Res= 64.9 kOhm Power= 100.0 mW Tolerance= 1.0%; Texas Instruments; LMR38020DDAR; Switcher; DDA0008E_N 55 mm²

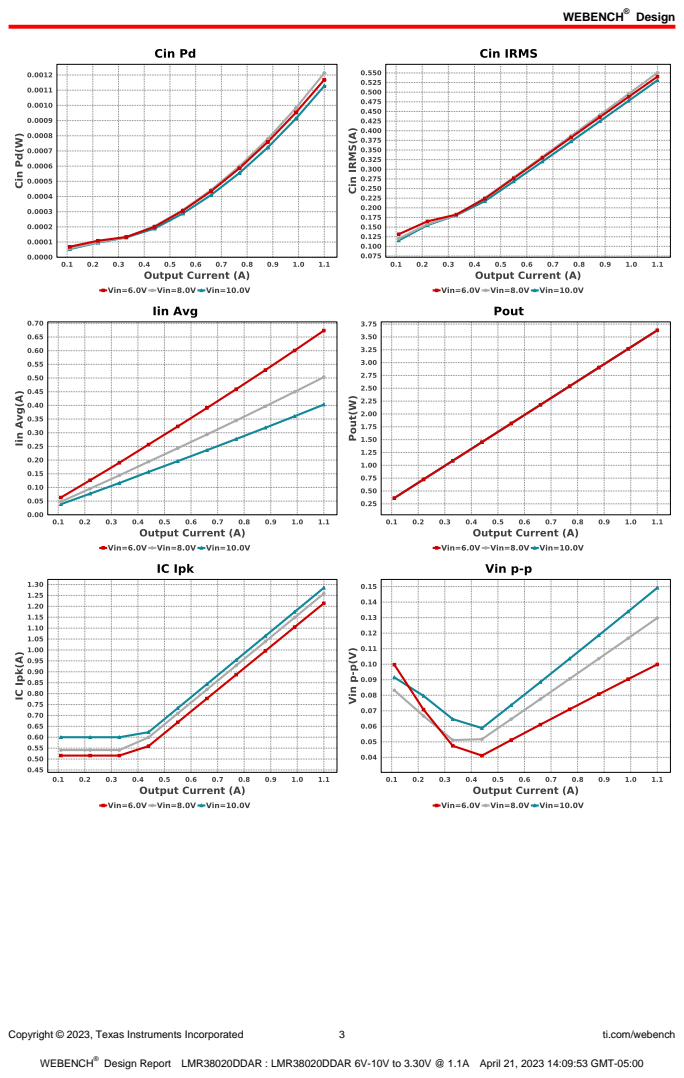
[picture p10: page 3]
Copyright © 2023, Texas Instruments Incorporated; ti.com/webench

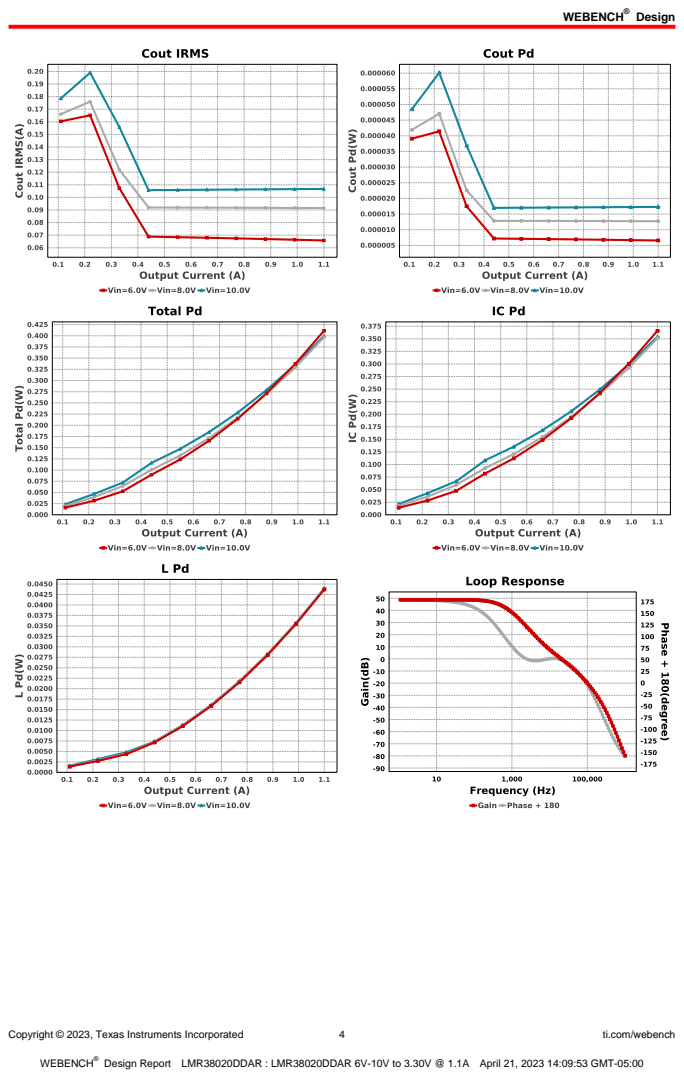
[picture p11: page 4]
Copyright © 2023, Texas Instruments Incorporated; ti.com/webench

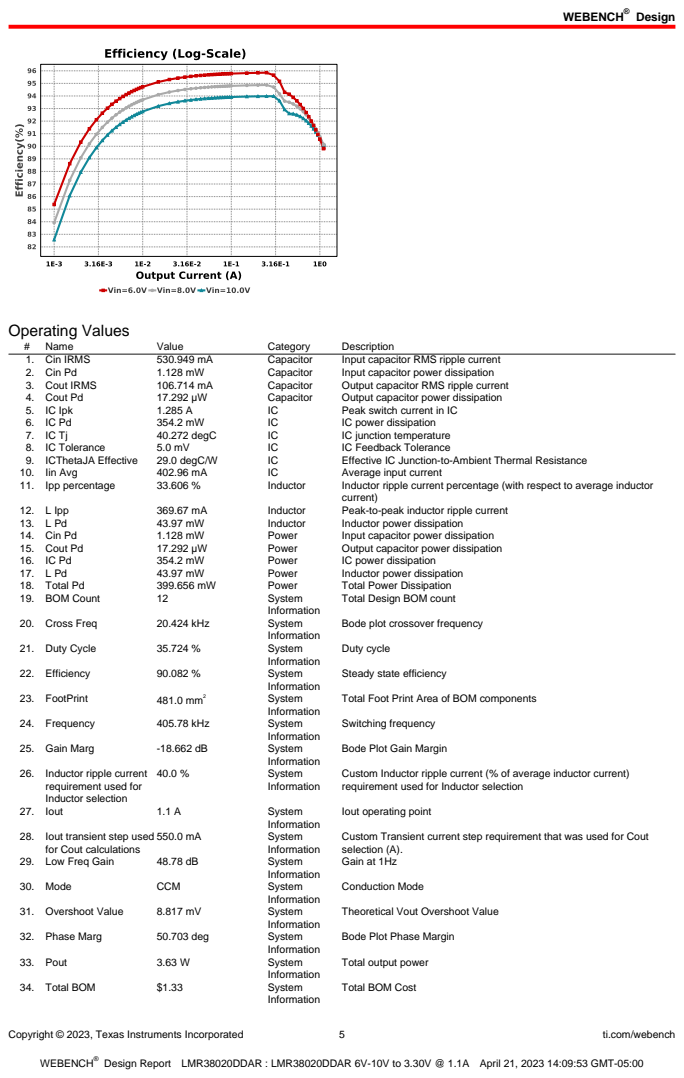
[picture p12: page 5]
Copyright © 2023, Texas Instruments Incorporated; ti.com/webench; Operating Values; Name; Value; Category; Description; 1. Cin IRMS; Capacitor; Input capacitor RMS ripple current; 2. Cin Pd; Input capacitor power dissipation; 3. Cout IRMS; Output capacitor RMS ripple current; 4. Cout Pd; Output capacitor power dissipation; 5. IC Ipk; Peak switch current in IC; IC power dissipation; 40.272 degC; IC junction temperature; 8. IC Tolerance; IC Feedback Tolerance; 9. ICThetaJA Effective; 29.0 degC/W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

Total Design BOM count

Bode plot crossover frequency

Steady state efficiency

Total Foot Print Area of BOM components

Bode Plot Gain Margin

26. Inductor ripple current
requirement used for
Inductor selection

Custom Inductor ripple current (% of average inductor current)
requirement used for Inductor selection

Iout operating point

28. Iout transient step used
for Cout calculations

Custom Transient current step requirement that was used for Cout
selection (A).
Gain at 1Hz

Theoretical Vout Overshoot Value

Bode Plot Phase Margin

Total output power

Total BOM Cost

Copyright © 2023, Texas Instruments Incorporated | 6 | ti.com/webench
# | Name | Value | Category | Description

35. Undershoot Value | 15.99 mV | System
| | | Information | Theoretical Vout Undershoot Value
36. Vin | 10.0 V | System
| | | Information | Vin operating point
37. Vin p-p | 149.193 mV | System
| | | Information | Peak-to-peak input voltage
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

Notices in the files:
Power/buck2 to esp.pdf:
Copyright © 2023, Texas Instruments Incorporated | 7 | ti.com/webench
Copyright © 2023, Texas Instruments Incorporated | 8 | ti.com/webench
